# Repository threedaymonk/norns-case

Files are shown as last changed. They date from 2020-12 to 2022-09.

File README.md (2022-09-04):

# Norns shield case extras

[What is a Norns shield?](https://github.com/monome/norns-shield)

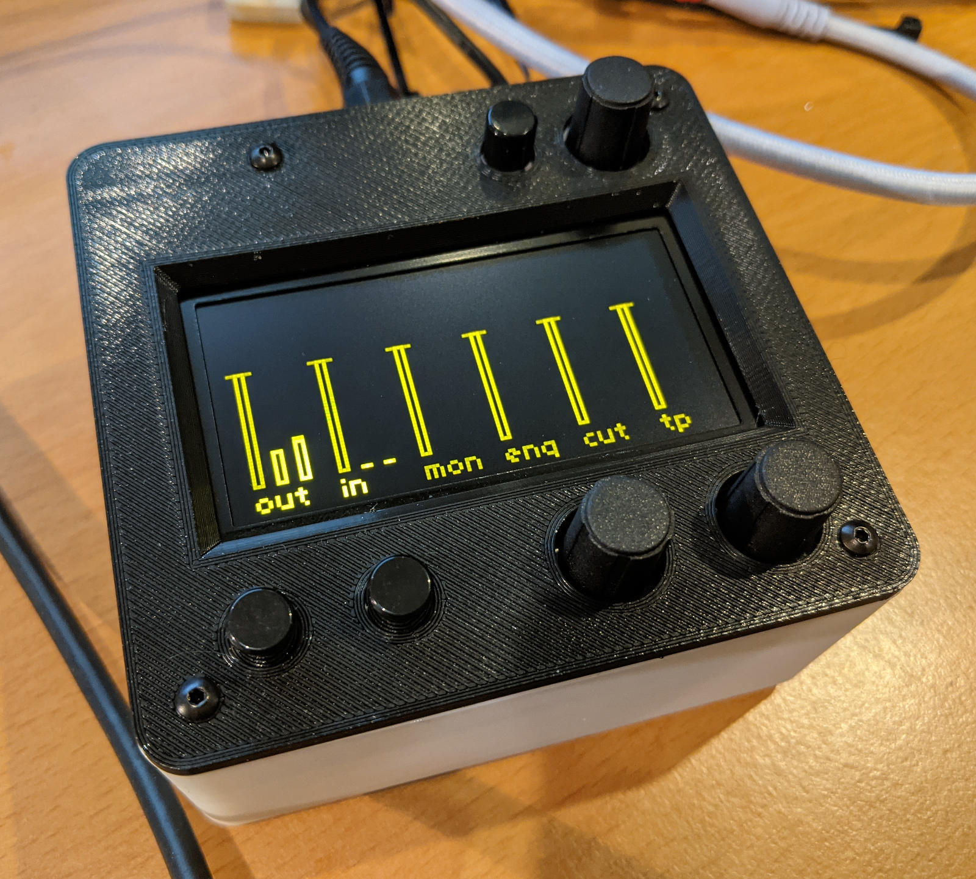
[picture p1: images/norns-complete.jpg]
Complete device


## Metric-friendly base

This is rebuilt from scratch to the same dimensions as [JHC's original
design](https://llllllll.co/t/norns-shield-case-designs/30347/224) with a few
changes.

Rather than the US standoffs and spacers that are hard to find in Europe, this
is designed to use metric hardware:

- 4 × M2.5 12mm long male-female standoffs
- 2 × M2.5 16mm long female standoffs
- 2 × M2.5 20mm long female standoffs
- 8 × M2.5 10mm button-head screw

For printing, a 0.2mm layer height is recommended. You can speed up the print
by printing solid vertical walls (set wall line count to a higher value than
usual).

## Screen support

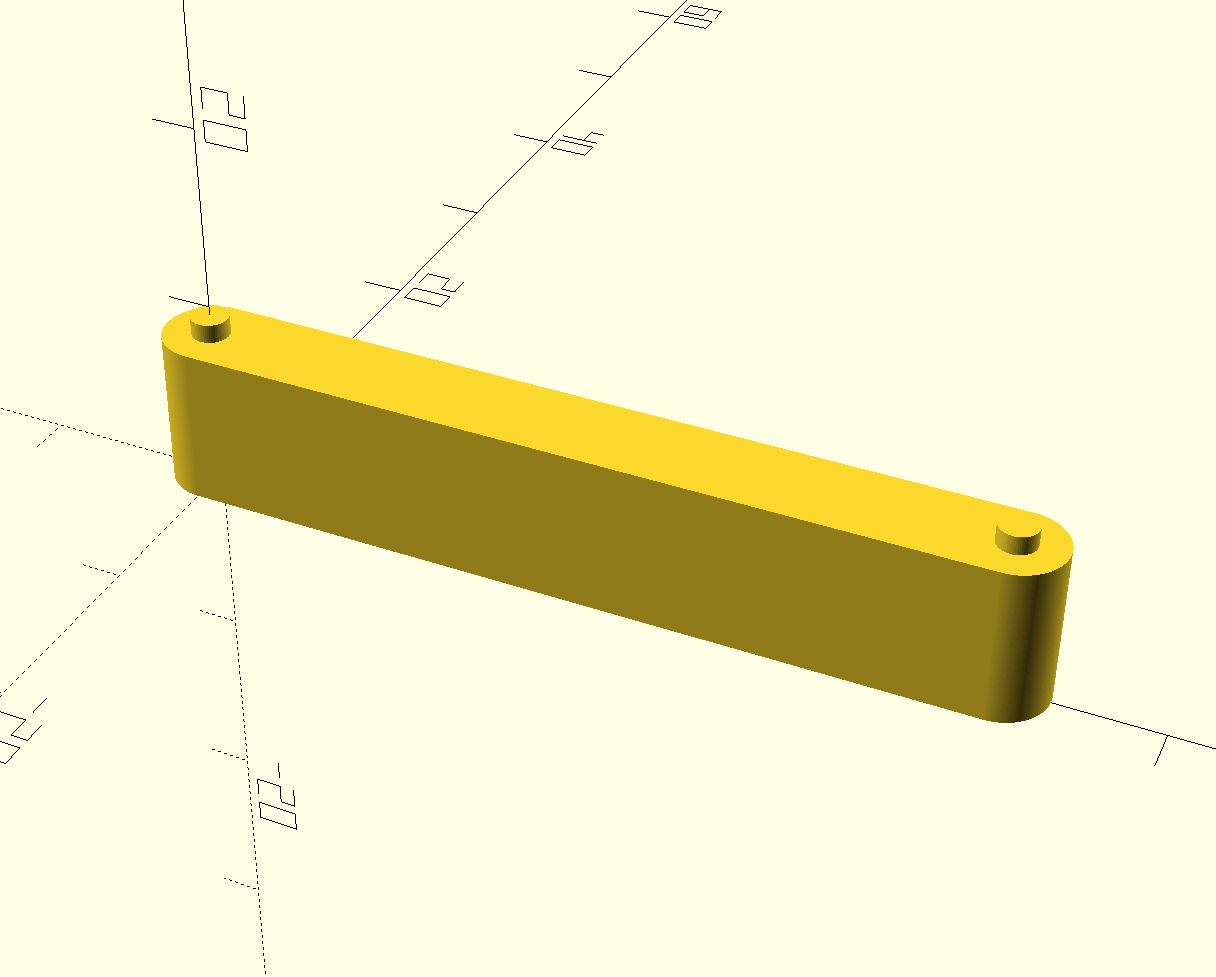
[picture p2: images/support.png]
Screen support block


These help to keep the screen horizontal and in place. They can be attached
between the screen and shield PCBs using a small piece of double-sided tape on
each side.

## Top plate

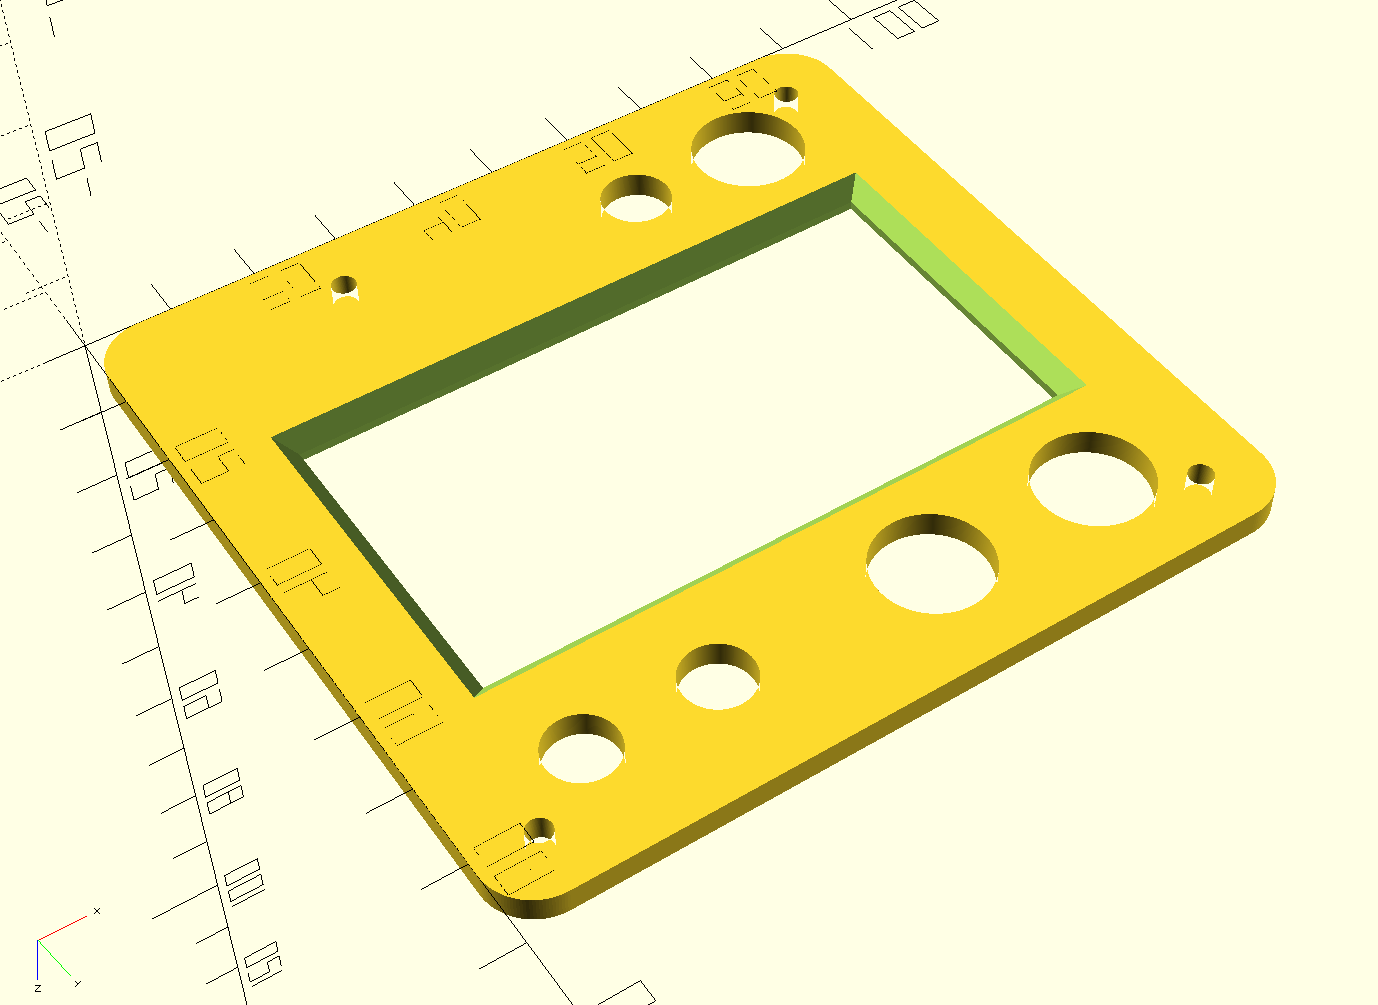
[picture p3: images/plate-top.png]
Top view


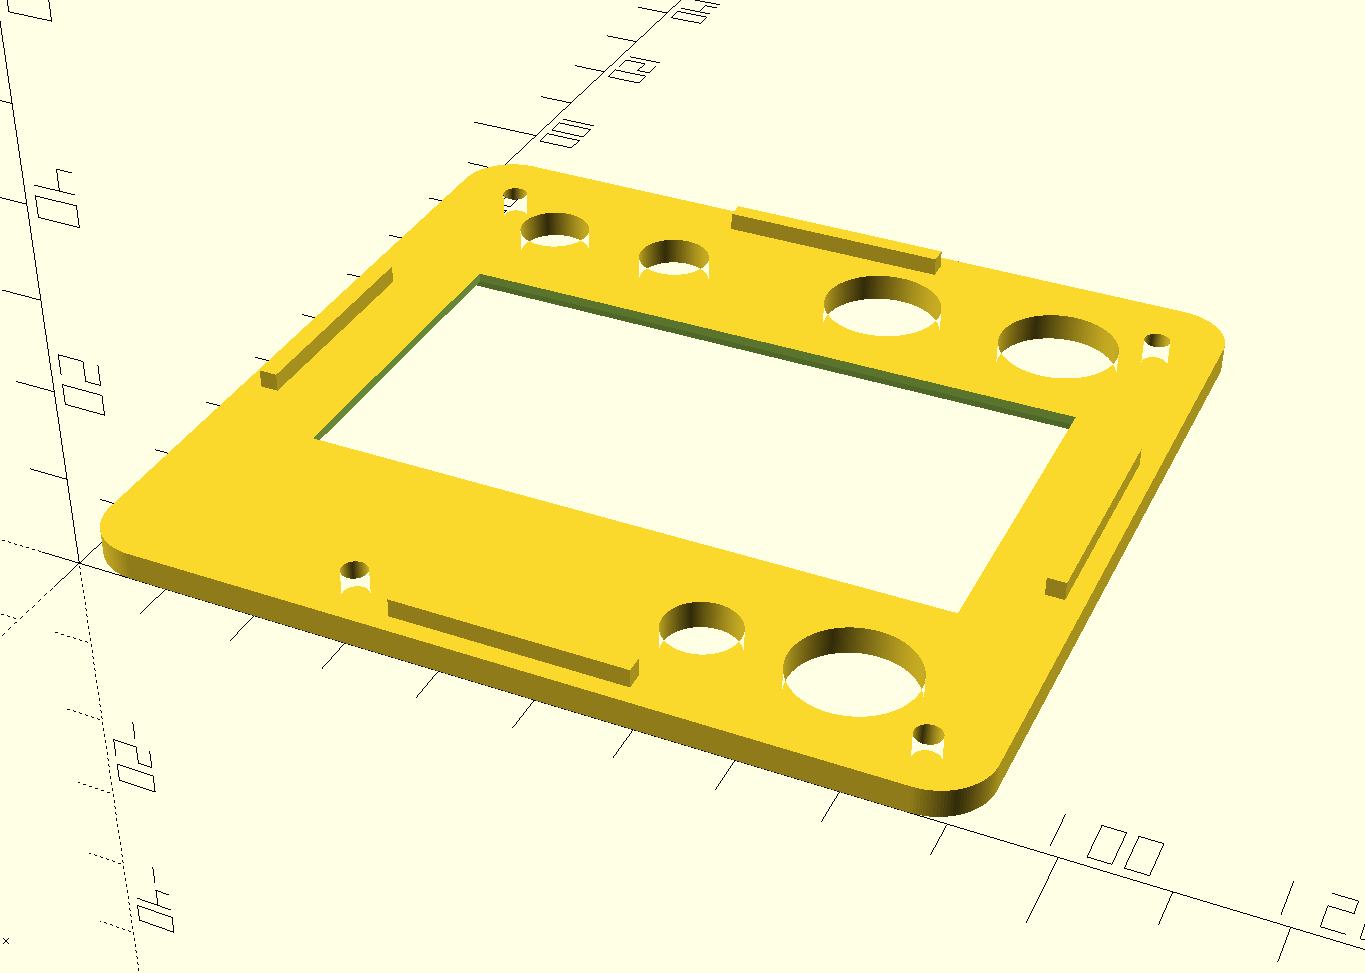
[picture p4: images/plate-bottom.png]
Bottom view


The thickness and dimensions of the knobs and buttons can be adjusted via the
appropriate variables.

The plate is intended to be printed upside down, so that the final upper
surface is on the print bed. On my printer, this gives a pleasing finish from
the textured bed.

The four blocks on the underside help to locate the plate and prevent the case
from flexing inwards.

This can be printed thicker (say 3.2mm) to be used as a top on its own without
the acrylic sheet.

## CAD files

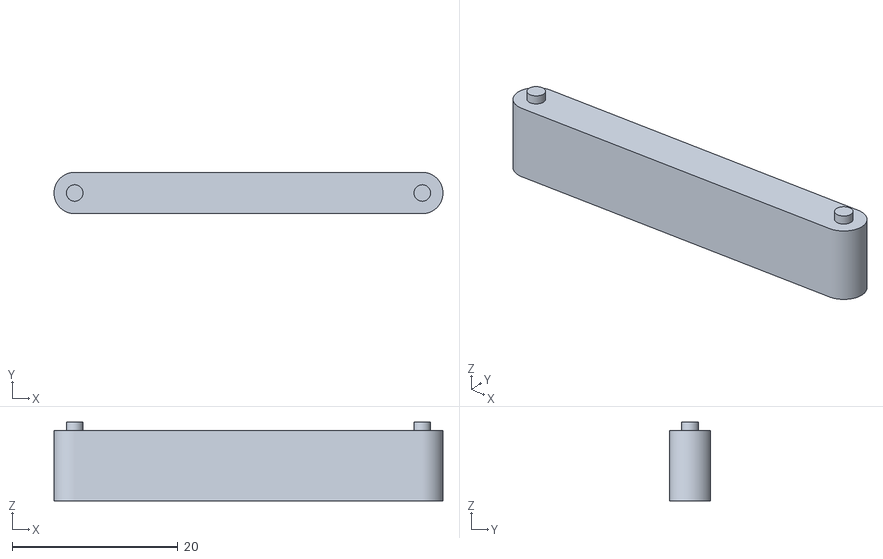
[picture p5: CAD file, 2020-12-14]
screen-support.stl
47.0 x 5.00 x 9.50

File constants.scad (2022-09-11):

$fs = $preview ? 1 : 0.1;
$fa = $preview ? 3 : 2;

layer = 0.2;

size_x = 92.5;
size_y = 87.5;
size_z = 40.0;

corner_r = 6;

wall_th = 2;
base_th = 3.2;

screw_hole_d = 3;
screw_head_d = 5.5;
screw_head_depth = 2;
screw_boss_inner_d = 4;
screw_boss_outer_d = 6;
screw_mounts = [
  // x, y, height above inner base
  [7.10, 7.10, 1.8],
  [85.5, 7.10, 1.8],
  [27.2, 80.3, 4.4],
  [85.5, 80.3, 4.4],
];

// These are reversed in y relative to screws
// because the top is printed upside down
//
kby_top = 12.8;
kby_bottom = kby_top + 62.2;
buttons = [
  [61.1, kby_top],
  [15.2, kby_bottom],
  [30.4, kby_bottom]
];
knobs = [
  [76.3, kby_top],
  [55.8, kby_bottom],
  [76.1, kby_bottom]
];

sockets = [
  // x, z
  [35.5, 22.6],
  [48, 22.6]
];

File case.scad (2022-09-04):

include <rounded.scad>
include <constants.scad>

module shell() {
  difference() {
    rounded_bottom_cube(
      [size_x, size_y, size_z],
      r = corner_r,
      square_off = 1
    );
    translate([wall_th, wall_th, base_th])
      rounded_bottom_cube(
        [size_x - 2 * wall_th,
         size_y - 2 * wall_th,
         size_z],
        r = corner_r - wall_th
      );
  }
}

module screw_boss_neg(thickness) {
  translate([0, 0, -1]) {
    cylinder(d = screw_head_d, h = screw_head_depth + 1);
    cylinder(d = screw_hole_d, h = thickness + 2);
  }
}

module screw_boss_pos(thickness, h) {
  translate([0, 0, thickness - 1])
    linear_extrude(height = 1 + h)
      difference() {
        circle(d = screw_boss_outer_d);
        circle(d = screw_boss_inner_d);
      }
}

module grill(length, width, pitch, count, h = 100) {
  translate([-pitch * floor(count / 2), 0, 0])
    for (i = [0 : count - 1])
      hull() for(j = [-1, 1])
      translate([pitch * i, (length - width) / 2 * j, 0])
        cylinder(d = width, h = h);
}

module negatives() {
  // Screw holes
  for (screw_mount = screw_mounts)
    translate([screw_mount[0], screw_mount[1], 0])
      screw_boss_neg(thickness = base_th);

  // Grill
  translate([size_x / 2, size_y / 2, -1])
    grill(length = 38, width = 2.4, pitch = 3.975, count = 9, h=10);

  // USB and network
  translate([-10, 28.5, 9.4]) rounded_cube([20, 15, 17.4], r = 1);
  translate([-10, 46.5, 9.4]) rounded_cube([20, 15, 17.4], r = 1);
  translate([-10, 65.0, 9.4]) rounded_cube([20, 16.5, 14.4], r = 1);

  // Micro SD
  translate([size_x - 6.2, 48.5, -10]) rounded_cube([20, 15.4, 18.4], r = 1);

  // Sockets
  for(xz = sockets)
    translate([xz[0], size_y, xz[1]]) rotate([90, 0, 0]) cylinder(d = 8, h = 20, center = true);

  // Power in
  translate([72.1, size_y - 10, 6.8]) rounded_cube([12.6, 20, 7.6], r = 1);

  // Feet
  foot_d = 10.5;
  foot_x = 10.9;
  foot_y = 14.4;
  foot_depth = 1.6;
  feet = [
    [foot_x, foot_y],
    [size_x - foot_x, foot_y],
    [foot_x, size_y - foot_y],
    [size_x - foot_x, size_y - foot_y],
  ];
  for (foot = feet)
    translate([foot[0], foot[1], -1])
      cylinder(d = foot_d, h = foot_depth + 1);

  // Blind connectors
  translate([31, size_y - wall_th - 1, 8]) cube([36, 1 + wall_th - 1.2, 9]);
}

module positives() {
  // Screw bosses
  for (screw_mount = screw_mounts)
    translate([screw_mount[0], screw_mount[1], 0])
      screw_boss_pos(thickness = base_th, h = screw_mount[2]);
}

difference() {
  shell();
  negatives();
}
positives();

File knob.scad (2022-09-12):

$fs = $preview ? 1 : 0.1;
$fa = $preview ? 3 : 2;
$e = 0.001;

// Main body diameter (mm) (at bottom, excluding skirt)
Diameter = 15;
// Total height (mm)
Height = 10;

ShaftDepth = 8.5; // [0.0:0.01:50.0]

// How far the shaft protrudes relative to the outer shell
// Negative values mean the shaft is inside the shell
ShaftOutset = 3;

// X/Y Offset to compensate for shrinking holes when printing. Increase if too tight. Decrease if too loose.
ShaftOffset = 0.18; // [-1.0:0.01:1.0]

KnurledShaftMajorDiameter = 6.0; // [3.0:0.01:15.0]

KnurlCount = 18;

// Knurled shaft.
// 6mm major diameter, 18 knurls, fits most pots.
module KnurledShaft(h, clearance=0, flare=0, d=6, count=18) {
  spacing = (d-2*clearance) * PI/count * 0.7;
  difference() {
    cylinder(h = h-clearance, d = d+2*clearance);
    SquareSerrations(h=h, d1=d+2*clearance, d2=d+2*clearance, fromz=0, toz=h,
      count=18, gapPct=30, rotationDeg=45, slant=0);
  }
  if (flare>0) Cone(h=d/2+flare*2, d=d+flare*2);
}

module SquareSerrations(h, d1, d2, fromz, toz, offset=0, count, gapPct=50, rotationDeg, slant) {
  baseD = DiameterAt(h, d1, d2, fromz);
  side = baseD*PI / count * (100-gapPct)/100;
  for (i=[0:count-1])
      rotate([0,0,360/count*i])
        translate([baseD/2+offset, 0, fromz])
          rotate([0, -slant, 0])
            rotate([0,0,rotationDeg])
              translate([-side/2, -side/2, 0])
                cube([side,side,toz-fromz]);
}

module Cone(h, d) {
  cylinder(h=h, d1=d, d2=0);
}

// Diameter of a slanted cylinder at height pos (lerp)
function DiameterAt(h, d1, d2, pos) = d1 - (d1-d2)*(pos/h);

module RoundedCylinder(h, d, r, corner_r=2) {
  r = (r == undef) ? d/2 : r;

  rotate_extrude() {
    intersection() {
      translate([r - corner_r, h - corner_r])
        circle(r = corner_r);
      square([r, h]);
    }
    polygon([
      [0, 0], [0, h], [r - corner_r, h], [r, h - corner_r], [r, 0]
    ]);
  }
}


rotate([180, 0, 0]) {
  difference() {
    union() {
      cylinder(h=Height, d=KnurledShaftMajorDiameter + 2);
      difference() {
        translate([0, 0, ShaftOutset])
          RoundedCylinder(h=Height, d=Diameter, corner_r=2);
        cylinder(h=ShaftDepth, d=Diameter - 4*0.4);
      }
    }
    translate([0, 0, -$e])
      KnurledShaft(h = ShaftDepth + $e,
                   flare=0.5,
                   clearance=ShaftOffset,
                   d=KnurledShaftMajorDiameter,
                   count=KnurlCount);
  }
}

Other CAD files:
rounded.scad
screen-support.scad
top-plate.scad

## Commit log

2020-12-14 Add source files
    [screen-support.scad, top-plate.scad]
2020-12-14 Add STL files for others' convenience
    [screen-support.stl, top-plate.stl]
2021-04-04 Fix STL
    [top-plate.stl]
2022-09-04 Mostly complete recreation of case
    [case.scad]
2022-09-04 Reduce height of lower bosses
    This words better with available metric standoffs. The Raspberry Pi PCB
    is 1.4mm, so given a 16mm standoff between the boards and a 20mm
    standoff on the overhanging part of the shield, the shorter bosses should
    be 2.6mm shorter than the taller ones.
    [case.scad]
2022-09-04 Square off the bottom radius for printing
    [case.scad]
2022-09-04 Move rounded shapes to included file
    Improved speed of fully rounded version based on
    https://gist.github.com/groovenectar/292db1688b79efd6ce11
    [case.scad]
2022-09-04 Make flat top rounded cube more efficient
    This implementation is over twice as fast as a hull around spheres and
    cylinders.
2022-09-04 Add text for IN and OUT
    [case.scad]
2022-09-04 Remove text, because I don't want it now
    [case.scad]
2022-09-04 Build everything from shared constants
    [acrylic.scad, case.scad, constants.scad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]
2022-09-04 Adjust dimensions for printing
    Everything is now quantised to a 0.2mm layer height.
    Wall thickness is 2.0mm, for a 0.4mm line width.
    [case.scad, constants.scad]
2022-09-04 Tweak USB and network ports
    [case.scad]
2022-09-04 Inset feet less deeply
    [case.scad]
2022-09-04 Remove STL files
    I'll use releases instead
    [top-plate.stl]
2022-09-04 Add triangles to acrylic
    These need to be manually post-processed in Inkscape
    [acrylic.scad]
2022-09-11 Correct lower button position
    As ever, it's not *quite* symmetrical!
    [constants.scad]
2022-09-11 New top plate design with acrylic glazing
    [constants.scad, rounded.scad, top-plate.scad]
2022-09-11 Make screws bigger to allow for paint
    [constants.scad]
2022-09-12 0.8mm is plenty for window surround
    [top-plate.scad]
2022-09-12 Remove clips, they don't work
    Instead, we'll leave a bit more space so that we can use adhesive. 5.5mm
    because I have some 5mm 3M 9448A tape.
    [top-plate.scad]
2022-09-12 Remove acrylic
    I'm using a 3D printed top with a window, because laser cutting is too
    pricey.
    [acrylic.scad]
2022-09-12 Remove arrows
    They don't come out very well, as the filament sags
    [top-plate.scad]
2022-09-12 Build knob (in parallel)
    [knob.scad]
